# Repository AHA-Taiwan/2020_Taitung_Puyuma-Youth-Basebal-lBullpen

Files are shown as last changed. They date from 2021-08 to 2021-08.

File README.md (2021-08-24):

# 2020｜台東卑南｜少棒木構牛棚
## _Puyuma Youth Baseball Bullpen_, Taitung, Taiwan

>Humanitarian Architecture in Taitung<br/>
>
以台灣國產木材為主體構築材料之人道建築案例，主要材料來源自：行政院農業委員會林務局「台灣木材」標章、正昌製材有限公司「柳杉」及東皇昌五金工具有限公司。由與木製研設計，公東高工、大安高工與交通大學等學校單位合作進行實作，計畫透過國產材木構設計改善偏鄉少棒練習環境。<br/>

## 基地環境：<br/>
台灣東南地區，北回歸線以南，有焚風、颱風、東北季風，海風具高度鹽分，設計時需注意材料防潮防蝕保護。<br/>
* 基地環境氣象資料：https://www.cwb.gov.tw/V8/C/W/County/County.html?CID=10014 <br/>
* 氣象觀測歷史紀錄：<br/>
  https://e-service.cwb.gov.tw/HistoryDataQuery/DayDataController.do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 <br/>

* 台東縣氣候月平均氣溫、月平均降雨量、風速與相對濕度數據圖表<br/>
 （取自交通部中央氣象局，統計期間為 1991-2020 年）<br/>



* Google Map 位置：https://goo.gl/maps/4CSL8ehEizMw4Z4f6<br/>

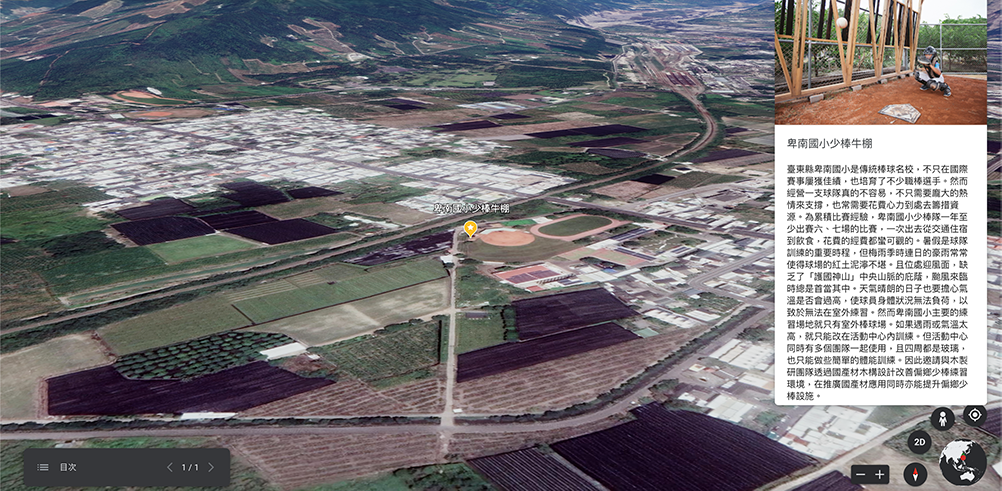
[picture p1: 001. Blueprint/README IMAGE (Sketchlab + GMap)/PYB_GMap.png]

***
## 專案介紹：<br/>
* 主要建材：台灣杉 [ 14.4 x 3 x 360 cm ]、[ 14.4 x 4.2 x 360 cm ] 和 [ 9.6 x 4.2 x 360 cm ] 尺寸。
* 數位模型［ 整體木構 3D ］：<br/>

捕手位置 Catcher's Position<br/>
Digital Model Link: https://skfb.ly/ooMID<br/> 
<br/>
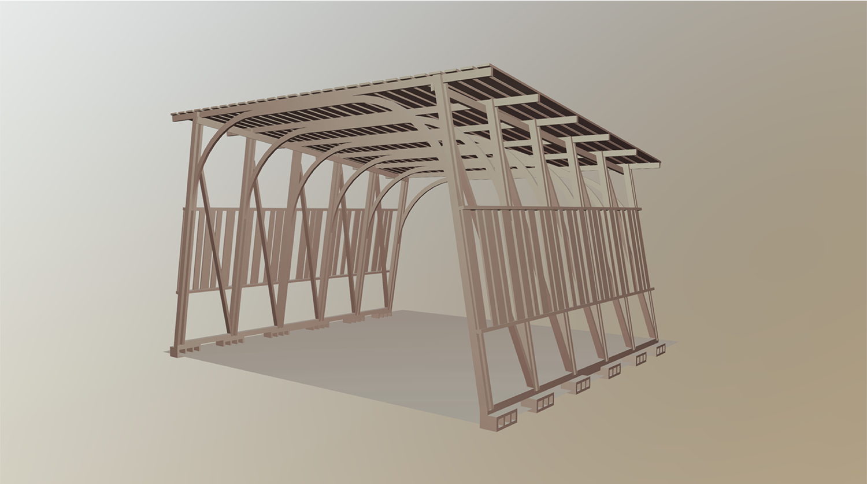
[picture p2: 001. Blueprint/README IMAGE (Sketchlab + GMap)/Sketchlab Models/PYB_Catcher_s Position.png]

<br/>
<br/>
投手位置 Pitcher's Position<br/>
Digital Model Link: https://skfb.ly/ooMI8<br/>
<br/>
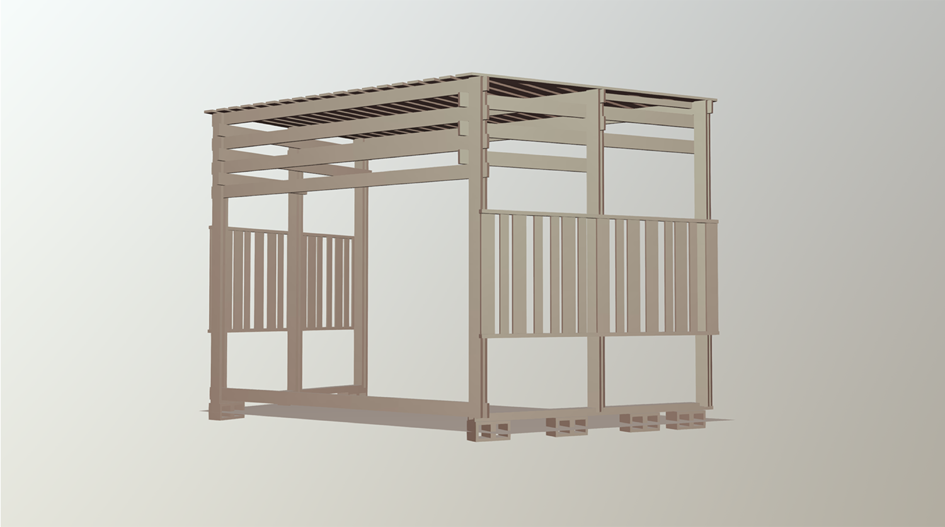
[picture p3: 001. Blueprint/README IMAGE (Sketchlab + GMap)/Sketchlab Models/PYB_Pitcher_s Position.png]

<br/>
<br/>
捕手區施工步驟（Construction Process of the Catcher's Position）<br/>
<br/>
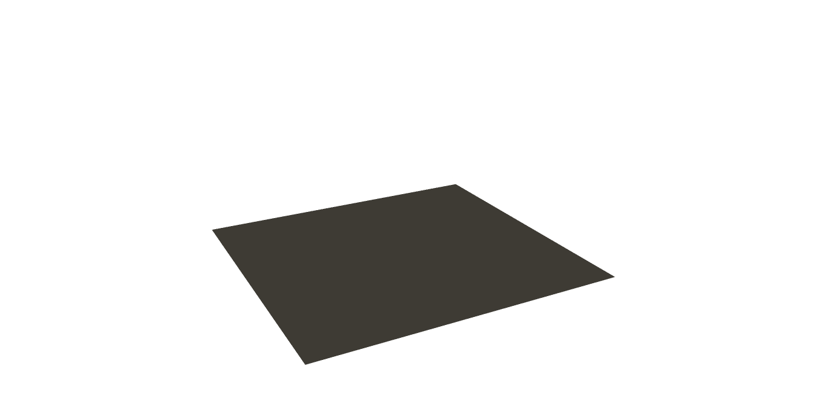
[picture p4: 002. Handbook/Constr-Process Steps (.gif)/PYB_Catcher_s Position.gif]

<br/>
<br/>
投手區施工步驟（Construction Process of the Pitcher's Position）<br/>
<br/>
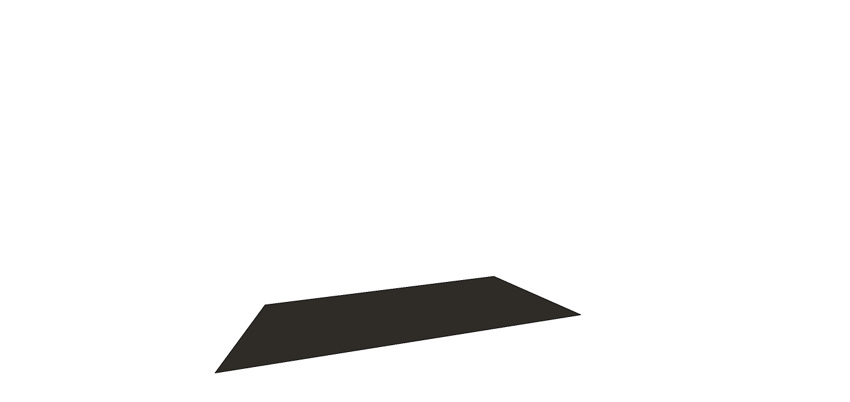
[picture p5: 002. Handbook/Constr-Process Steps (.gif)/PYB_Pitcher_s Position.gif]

<br/>
<br/>
***
## 如何達成合作建造：<br/>
* 請參閱［初次合作建造就上手 Collab-Const-Quick-Guide］：<br/>
https://github.com/AHA-Taiwan/Collab-Const-Quick-Guide/wiki <br/>
***
## 確保工作安全：<br/>
* 請參閱［合作建造-安全規範 Collab-Const-Safety］：<br/>
https://github.com/AHA-Taiwan/Collab-Const-Safety/wiki <br/>
***
## 探索合作資源：<br/>
* 請參閱［合作建造-資源探索 Collab-Const-Source］：<br/>
https://github.com/AHA-Taiwan/Collab-Const-Source/wiki <br/>
***
## 取得建造知識：<br/>
* 關於一般的常用構造技術（Techniques），請參閱［合作建造-學習知識 Collab-Const-Learning］：<br/>
https://github.com/AHA-Taiwan/Collab-Const-Learning/wiki <br/>
* 關於本案的特殊構築技術（Tectonic）， 請參閱［本案資料夾 002. Handbook］：<br/>
https://github.com/AHA-Taiwan/2020_Taitung_Puyuma-Youth-Baseball-Bullpen/tree/master/002.%20Handbook<br/>
***

> #### 歡迎參與專案開發，Branch合併可向專案管理者提出請求

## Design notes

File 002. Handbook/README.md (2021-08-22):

Assembly Drawing--組裝圖面<br/>
Assembly-Object Coding--物件組裝編碼<br/>
Constr-Process Handbook (pdf+ppt)--施工手冊與簡報<br/>
Constr-Process Sheet (.doc)--工項工序表<br/>
Constr-Processs Steps (.gif)--動態組裝圖<br/>
<br/>
Construction Method (photos)--施工工法<br/>
Link: https://drive.google.com/drive/folders/1FZwmxR8_8e2cyzcdbKTD-9hDnzFZ1XvT?usp=sharing<br/>

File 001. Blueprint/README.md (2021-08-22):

2D CAD (.dwg)<br/>
2D JPG<br/>
3D Models<br/>
3D Pictures<br/>
README IMAGE (Gmap & Sketchfab)<br/>

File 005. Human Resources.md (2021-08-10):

# 專業者佈局與人力成本紀錄 
主要紀錄整體施工過程中，專業者、準專業者、非專業者於不同工項所花費時數，從中可間接推估建造施工人力經費及時間成本。
專業者M、準專業者P、非專業者N，當地人加註C

## 一、基礎施工
|人力編碼|當地人|工作總時數(hrs)|請工|換工|志工|
|:-:|:-:|:-:|:-:|:-:|:-:|
|M01 | |12 | | |V |
|M02 | |12 | | |V |
|M03 | |12 | | |V |
|M04 | |12 | | |V |
|P01 | |12 | | |V |
|P02 | |12 | | |V |
|P04 | |12 | | |V |
|P05 | |12 | | |V |
|P06 | |12 | | |V |
|P07 | |12 | | |V |
|P08 | |12 | | |V |
|P09 | |12 | | |V |
|P010 | |12 | | |V |
***
## 二、捕手區結構
|人力編碼|當地人|工作總時數(hrs)|請工|換工|志工|
|:-:|:-:|:-:|:-:|:-:|:-:|
|M01 | |32 | | |V |
|M02 | |32 | | |V |
|M03 | |32 | | |V |
|M04 | |32 | | |V |
|P01 | |32 | | |V |
|P02 | |32 | | |V |
|P04 | |32 | | |V |
|P05 | |32 | | |V |
|P06 | |32 | | |V |
|P07 | |32 | | |V |
|P08 | |32 | | |V |
|P09 | |32 | | |V |
|P010 | |32 | | |V |
***
## 三、投手區結構
|人力編碼|當地人|工作總時數(hrs)|請工|換工|志工|
|:-:|:-:|:-:|:-:|:-:|:-:|
|M01 | |24 | | |V |
|M02 | |24 | | |V |
|M03 | |24 | | |V |
|M04 | |24 | | |V |
|P01 | |24 | | |V |
|P02 | |24 | | |V |
|P04 | |24 | | |V |
|P05 | |24 | | |V |
|P06 | |24 | | |V |
|P07 | |24 | | |V |
|P08 | |24 | | |V |
|P09 | |24 | | |V |
|P010 | |24 | | |V |
***

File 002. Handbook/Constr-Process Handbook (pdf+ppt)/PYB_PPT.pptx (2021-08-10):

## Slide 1

2020

卑南義築．工作手冊

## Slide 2

目錄

一．活動簡述．．．．．．．．．．．．１
二．自備物品與重要叮嚀．．．．．．．２
三．每日作息與行事曆．．．．．．．．４
四．交通與地圖．．．．．．．．．．．６
五．附件．．．．．．．．．．．．．．７
值日生班表
各組分工負責人
通訊錄
牛棚設計圖面
木材尺寸

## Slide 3

１

一．活動簡述

時間：2020年8月19日 —2020年8月28日
地點：台東縣卑南鄉卑南國小（台東縣台東市更生北路317號）
住宿：卑南國小主題教室

夏天是明亮的，太陽是辣的，
青春的心是熱血的。
離開了繁華，重返樸實；
捨棄了依賴，回歸自立。

參與團體

外界交流

大愛電視台
聯新文教基金會

台東縣政府文化處
公東高工
家具木工科／室內設計科／建築科
納樊斯木工作室
義築工具圖書館
老麥農場露營區
社團法人台東縣巴蘭文化發展協會
社團法人台灣義築協會

材料贊助

行政院農委會林務局
正昌製材（台灣杉）
誠豐木業（黃檜木）
東皇昌五金行

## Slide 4

２

二．自備物品與重要叮嚀

換洗衣物 | 輕便工作服／衣架／曬衣夾／塑膠袋／洗衣用具／肥皂
盥洗用品 | 潔牙用品／毛巾／沐浴用品／吹風機
個人衛生品 | 衛生紙／濕紙巾／生理用品
個人藥物 | 健保卡／防蚊液／防曬乳／藥膏／個人用藥
必備物品 | 手電筒／睡袋／麥克筆／抹布
餐具 | 環保餐具／水壺
其他 | 帽子／外套／雨具／筆記／糧食／相機／袖套 足夠的零用金＆快樂心

重要叮嚀

1. 校園蛇類出沒，夜間活動務必攜帶手電筒，並尊重當地生態環境 。
2. 為避免影響施工進度，請按作息表活動，請勿飲酒 。
3. 避免使用香味濃郁的盥洗用品，易引來蚊蟲 。
4. 請留意貴重物品 。
5. 請注意當地禁忌，活動請結伴同行 。
6. 當地提款與融資服務不便，請攜帶足夠的現金 。
7. 施工區域內請著長褲及全包覆鞋，勿穿拖鞋或涼鞋，並時時補充水分。
8. 由於浴室數量有限，洗澡時間限制十分鐘。

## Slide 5

３

最重要的三件事！！
1. 晚間收工前30分鐘，清點材料、工具
2. 收工前15分鐘，整理工作環境
3. 工地危險，務必攜帶安全帽著長褲及全包覆鞋，勿著涼拖鞋
-工具配件務必妥善放回它的位置，切勿亂放
-建材勿隨意放置，會影響材料品質與建築壽命
-廢料勿扔棄，做好資源管理，這是對建築過程的尊重
-離隊務必告知組員、組長，個人行為將影響全體
-注意言行、態度，對自己負責，也尊重合作夥伴
-我們是一個大團體，務必保持與其他單位的良好互動
-我們是一個共同體，請關心身邊的伙伴，發揮自己的價值

施工注意事項

做一個謙卑的實踐者，感恩這份學習的機會

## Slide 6

４

三．每日作息與行事曆

（時間可能依每日天候狀況有所調整）

時間 | 活動 | 備註
0600 | Good Morning | 宿舍長叫醒大家
0600–0630 | 盥洗準備
0630–0700 | 活力早餐 | 生活組提前準備
0700–1130 | 牛棚建起來 | 施工組開工
1130–1300 | 午餐輕巧吃 | 生活組準備
1300–1700 | 牛棚繼續建起來 | 施工組開工
1700–1800 | 洗澎澎 | 超時斷水電！
1800–1930 | 晚餐時光 | 生活組準備
1930–2100 | 工作會議 | 進度／工地狀況檢討
2100–2200 | 小組／個人時間 | 工作日誌／影音整理
2200 | 睡飽睡好

生活值日生工作
1. 工作環境整理
2. 餐後、廚餘整理
3. 清洗、收拾餐具
4. 搬運、發放食物

住宿值日生工作
1. 寢室環境清潔
2. 廁所清潔及垃圾清理
3. 浴廁清潔

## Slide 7

５

行事曆

08/19 （三）

認識大家／基礎前置加工

08/21 （五）

08/20 （四）

08/23 （日）

08/22 （六）

08/24 （一）

08/25 （二）

08/26 （三）

08/27 （四）

08/28 （五）

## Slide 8

６

四．交通與地圖

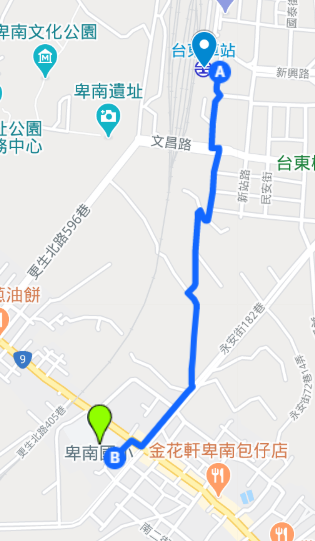
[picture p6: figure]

集合

加工、施工

住宿

※ 抵達臺東車站後，基本上都是縣府派車支援！

由　臺東車站　前往　初鹿國中

步行（15分鐘）至南王站牌
搭乘8171號公車（45分鐘）至初鹿國中

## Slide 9

７

五．附件

各組分工負責人

生活
交通／宿舍長
工程
工具
材料
攝影
護理

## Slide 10

10

牛棚設計圖面

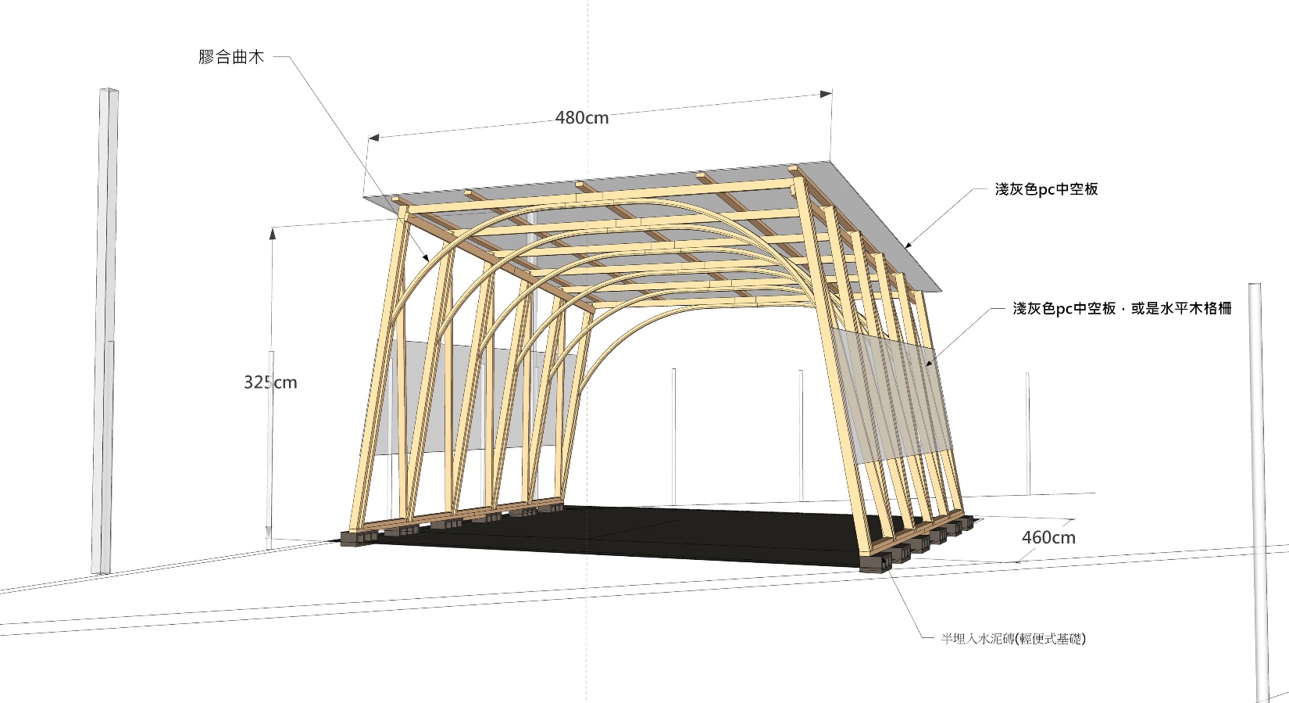
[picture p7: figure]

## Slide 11

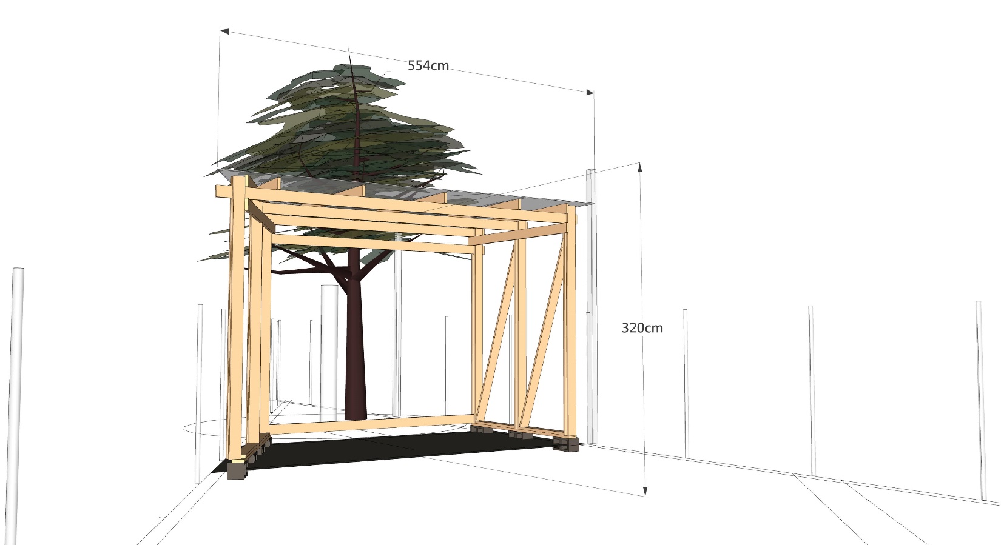
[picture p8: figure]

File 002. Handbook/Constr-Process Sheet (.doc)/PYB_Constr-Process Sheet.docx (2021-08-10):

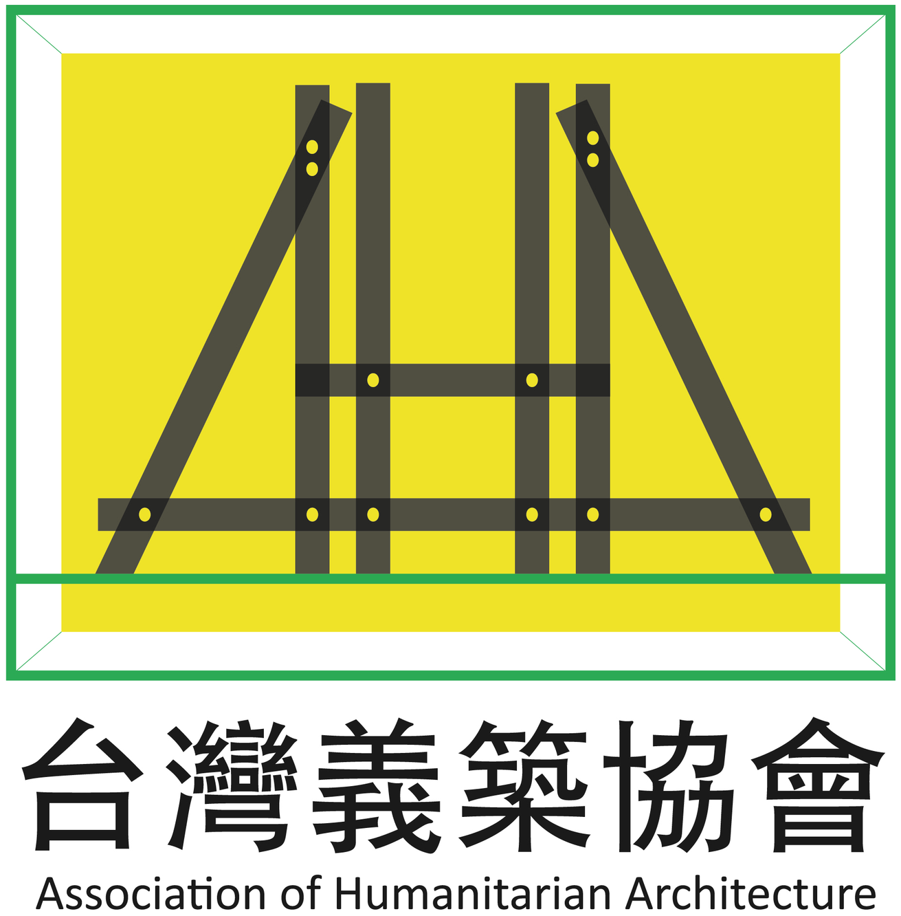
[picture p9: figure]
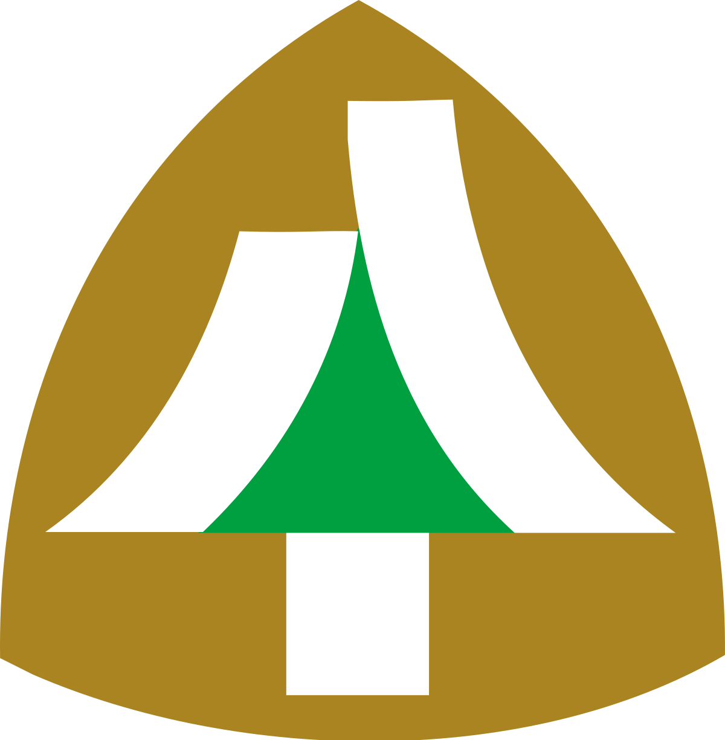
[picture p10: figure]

2020年 台東卑南少棒牛棚 義築作品

生產製程文件

作業名稱 | 一、構件預製 | 項次 | 作業順序 | | 備註

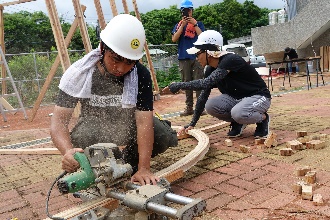
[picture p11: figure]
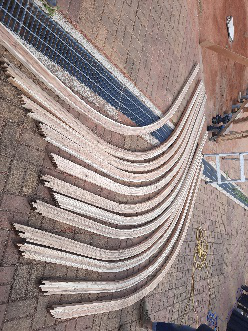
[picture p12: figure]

項次1-2 項次1 項次2 | | 1 | 預製曲樑 | | 與木製研工廠預製
| | 2 | 將木材切割至構件尺寸
| | 項次 | 原料 | 設備 | 站別
| | a | 斷面14.4*4.2cm木料 斷面14.4*3cm木料 斷面9.6*4.2cm木料 | 工作臺 | 加工區
| | b | 斷面14.4*4.2cm木料 斷面14.4*3cm木料 斷面9.6*4.2cm木料 | 角切機 | 切割區

作業名稱 | 二、燒杉 | 項次 | 作業順序 | | 備註

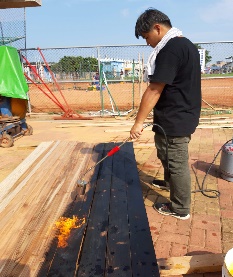
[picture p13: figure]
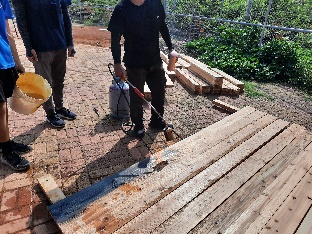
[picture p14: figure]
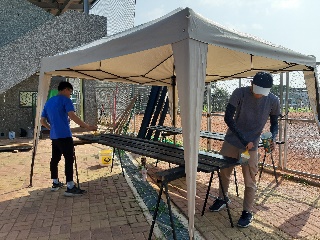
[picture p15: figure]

項次1-2 項次1 項次2 | | 1 | 燒杉
| | 2 | 冷卻
| | 3 | 確認燃燒程度
| | 4 | 上保護漆
| | 項次 | 原料 | 設備 | 站別
| | a | 斷面14.4*4.2cm木料 斷面14.4*3cm木料 斷面9.6*4.2cm木料 | 火槍 瓦斯 | 燒杉區
| | b | 斷面14.4*4.2cm木料 斷面14.4*3cm木料 斷面9.6*4.2cm木料 | 灑水 | 燒杉區
項次3 項次4 | | c | 斷面14.4*4.2cm木料 斷面14.4*3cm木料 斷面9.6*4.2cm木料 | 目視 | 燒杉區
| | d | 斷面14.4*4.2cm木料 斷面14.4*3cm木料 斷面9.6*4.2cm木料 | 油漆刷 護木漆 | 油漆區

作業名稱 | 三、捕手區結構施工 | 項次 | 作業順序 | | 備註

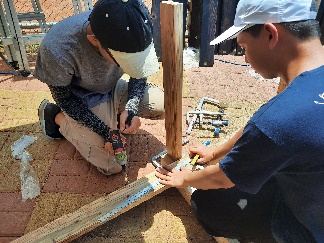
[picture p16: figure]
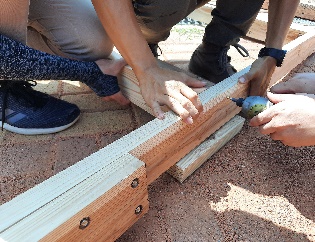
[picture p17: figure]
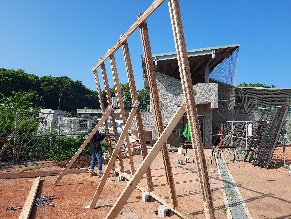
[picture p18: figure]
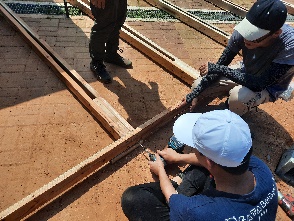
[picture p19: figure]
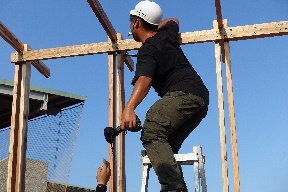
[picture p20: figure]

項次1 項次2 項次3 項次4 項次5 項次6 | | 1 | 接合延長木頭
| | 2 | 放樣立柱位置
| | 3 | 立柱於基座上
| | 4 | 斜撐假固定
| | 5 | 上大樑
| | 6 | 上曲樑
| | 項次 | 原料 | 設備 | 站別
| | a | 已加工木料、螺桿 | 起子機、電鑽 | 組裝區
| | b | 已加工木料 | 尺、筆 | 組裝區
| | c | 已加工木料、螺桿 | 電鑽、起子機 | 組裝區
| | d | 木料 | 夾具 | 切割區
| | e | 已裁切木料、螺桿 | 起子機、電鑽 | 組裝區
| | f | 已裁切木料、螺桿 | 起子機、電鑽 | 組裝區

作業名稱 | 四、投手區結構施工 | 項次 | 作業順序 | | 備註

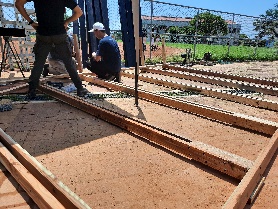
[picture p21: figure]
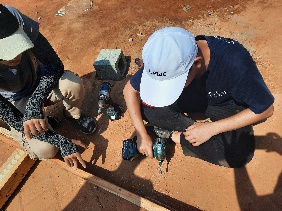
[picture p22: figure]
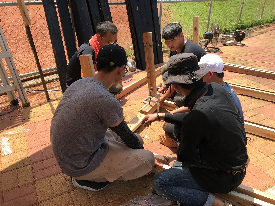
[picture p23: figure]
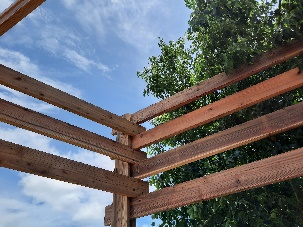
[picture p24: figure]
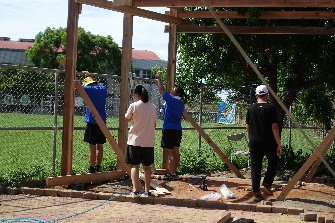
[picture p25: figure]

項次1 項次2 項次3 項次4 項次5 項次6 | | 1 | 接合延長木頭
| | 2 | 放樣立柱位置
| | 3 | 立柱於基座上
| | 4 | 後方橫樑施作
| | 5 | 側邊橫樑施作
| | 6 | 上大樑
| | 項次 | 原料 | 設備 | 站別
| | a | 已加工木料、螺桿 | 起子機、電鑽 | 組裝區
| | b | 已加工木料 | 尺、筆 | 組裝區
| | c | 已加工木料、螺桿 | 電鑽、起子機 | 裁切區
| | d | 已裁切木料、螺桿 | 電鑽、起子機 | 組裝區
| | e | 已裁切木料、螺桿 | 起子機、電鑽 | 組裝區
| | f | 已裁切木料、螺桿 | 起子機、電鑽 | 組裝區

作業名稱 | 五、上屋頂板 | 項次 | 作業順序 | | 備註

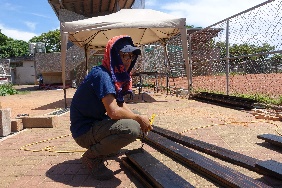
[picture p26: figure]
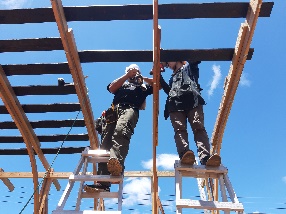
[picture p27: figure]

項次1 項次2 項次3 項次4 | | 1 | 確認組裝部件
| | 2 | 預排屋頂版位置
| | 3 | 釘槍固定接合處
| | 4 | 螺絲鎖上屋頂板
| | 項次 | 原料 | 設備 | 站別
| | a | 已燒杉木料 | 目視 | 組裝區
| | b | 已燒杉木料 | 人力 | 組裝區
| | c | 已燒杉木料 | 釘槍 | 組裝區
| | d | 已燒杉木料、螺絲 | 起子機 | 組裝區

作業名稱 | 六、窗框、窗板 | 項次 | 作業順序 | | 備註

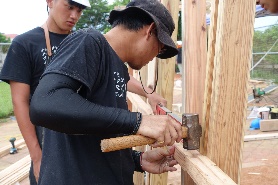
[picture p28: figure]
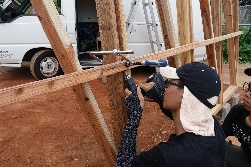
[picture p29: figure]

項次1 項次2 項次3 項次4 項次5 項次6 | | 1 | 下窗框引排水孔
| | 2 | 下窗框放樣、定水平
| | 3 | 上窗框定高度、水平
| | 4 | 假固定
| | 5 | 將窗框鎖於柱上
| | 6 | 放入窗板
| | 項次 | 原料 | 設備 | 站別
| | a | 已裁切木料 | 電鑽 | 組裝區
| | b | 已裁切木料 | 人力、水平尺、筆 | 組裝區
| | c | 已裁切木料 | 人力、水平尺、筆 | 組裝區
| | d | ----- | 夾具、釘槍 | 組裝區
| | e | 已裁切木料 | 電鑽、起子機 | 組裝區
| | f | 已燒杉木料 | 人力 | 組裝區

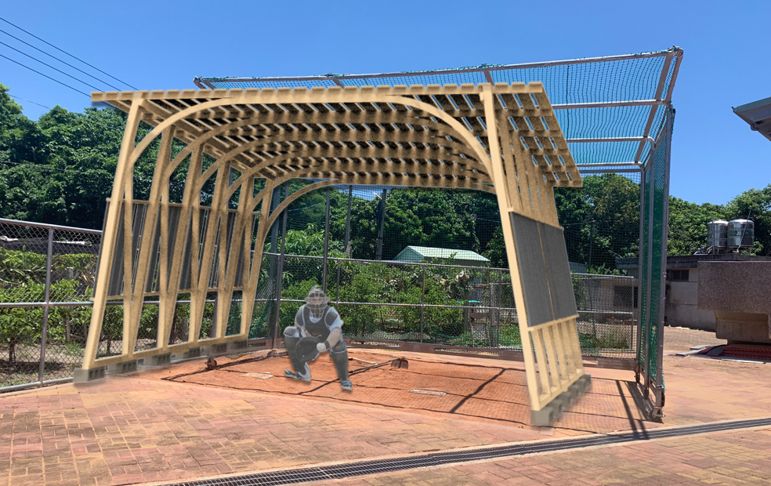
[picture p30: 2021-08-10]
001. Blueprint/3D Pictures/PYB_Catcher Side_Rendered.jpg

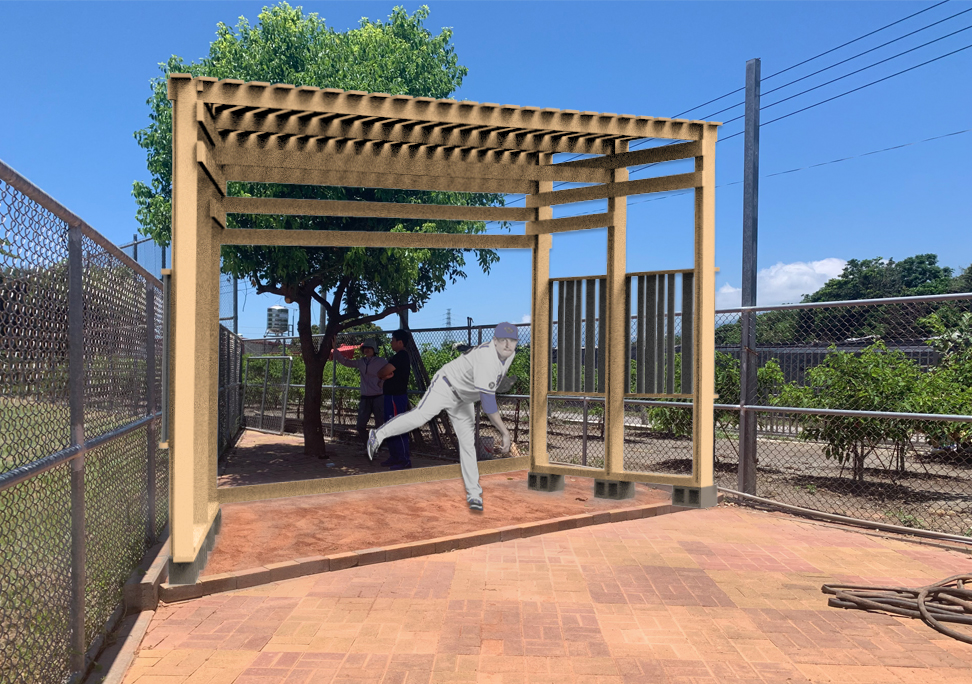
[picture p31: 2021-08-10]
001. Blueprint/3D Pictures/PYB_Pitcher Side_Rendered.jpg

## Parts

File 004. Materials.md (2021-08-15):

# 材料清單與部件編碼紀錄 
主要紀錄整體施工過程中，各部位構件之材料名稱、規格、數量、單價、材料來源、廠商資訊等，從中可推估材料經費及運輸成本。

## 主要建材
|編碼|材料名稱|部件位置|規格|需要數量|實購數量|材料來源|
|:-:|:-:|:-:|:-:|:-:|:-:|:-:|
|S001|柳杉|捕手區主體結構|9.6 x 4.2 x 360 cm|40|40|[正昌製材](http://www.wood.jen.com.tw/fengxi/front/bin/home.phtml)|
|S002|柳杉|投手區主體結構|14.4 x 4.2 x 360 cm|100|100|[正昌製材](http://www.wood.jen.com.tw/fengxi/front/bin/home.phtml)|
|S003|柳杉|屋頂平板|14.4 x 3 x 360 cm|100|100|[正昌製材](http://www.wood.jen.com.tw/fengxi/front/bin/home.phtml)|
***
## 五金材料
|編碼|材料名稱|部件位置|規格|數量|
|:-:|:-:|:-:|:-:|:-:|
|B001|護木漆||||
***

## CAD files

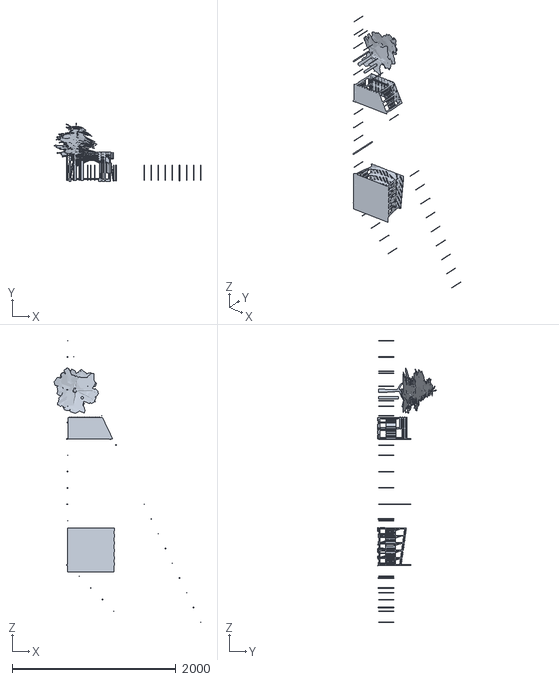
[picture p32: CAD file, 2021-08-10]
001. Blueprint/3D Models/PYB_Model.obj
1793.9 x 718.2 x 3447.3

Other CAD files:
001. Blueprint/2D CAD (.dwg)/PYB_Pitcher and Catcher_Model.dwg
001. Blueprint/2D CAD (.dwg)/PYB_Pitcher and Catcher_Plan.dwg
001. Blueprint/3D Models/PYB_Model(1).skp
001. Blueprint/3D Models/PYB_Model.3dm
001. Blueprint/3D Models/PYB_Model.skp

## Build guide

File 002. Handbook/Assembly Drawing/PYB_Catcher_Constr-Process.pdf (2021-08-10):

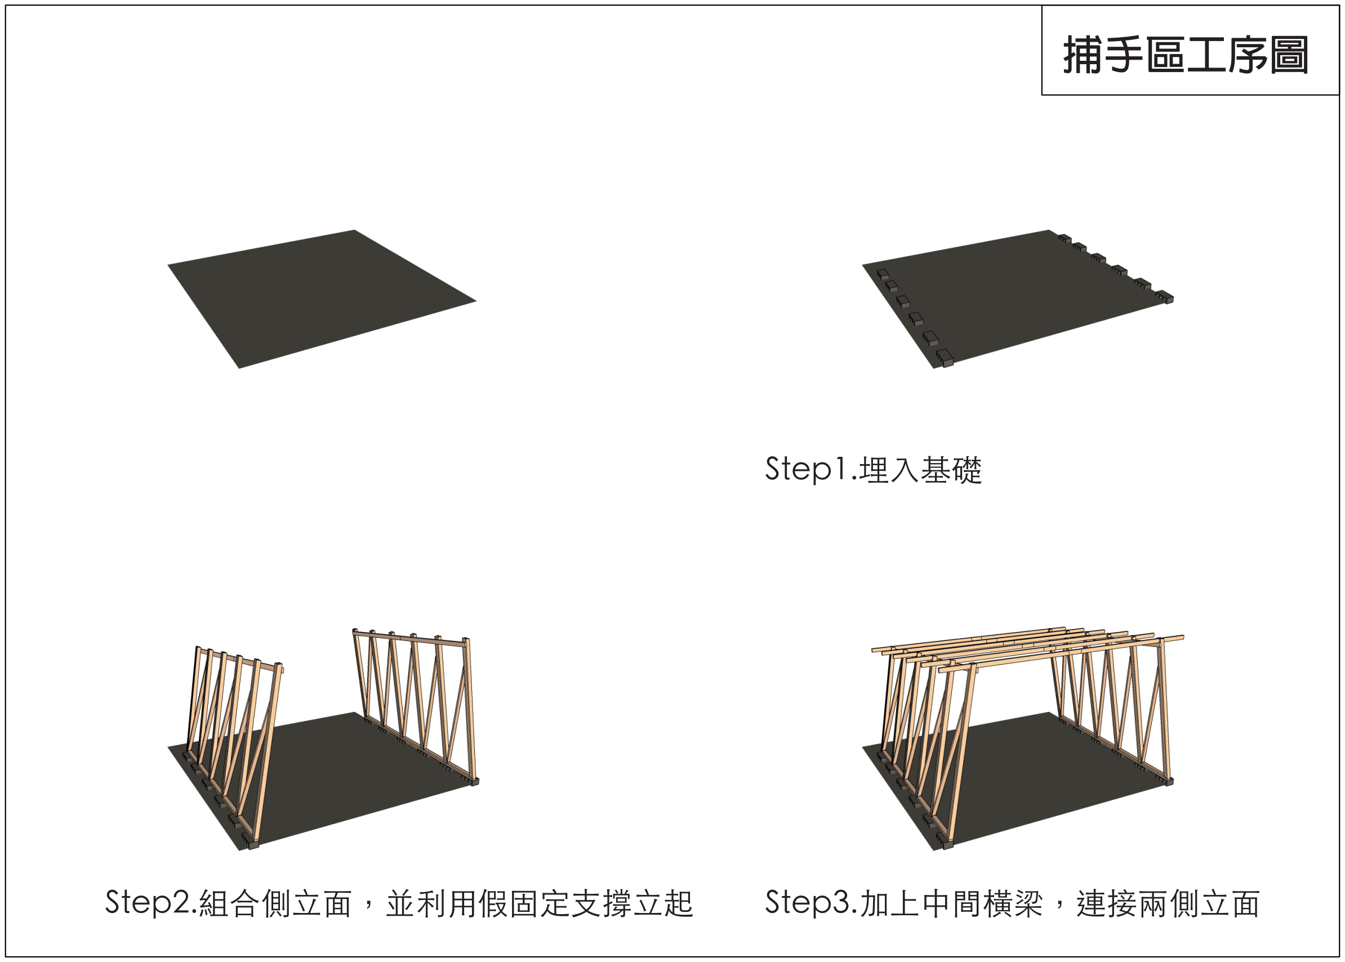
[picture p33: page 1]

Step2.組合側立面，並利用假固定支撐立起

Step1.埋入基礎

Step3.加上中間橫梁，連接兩側立面

捕手區工序圖

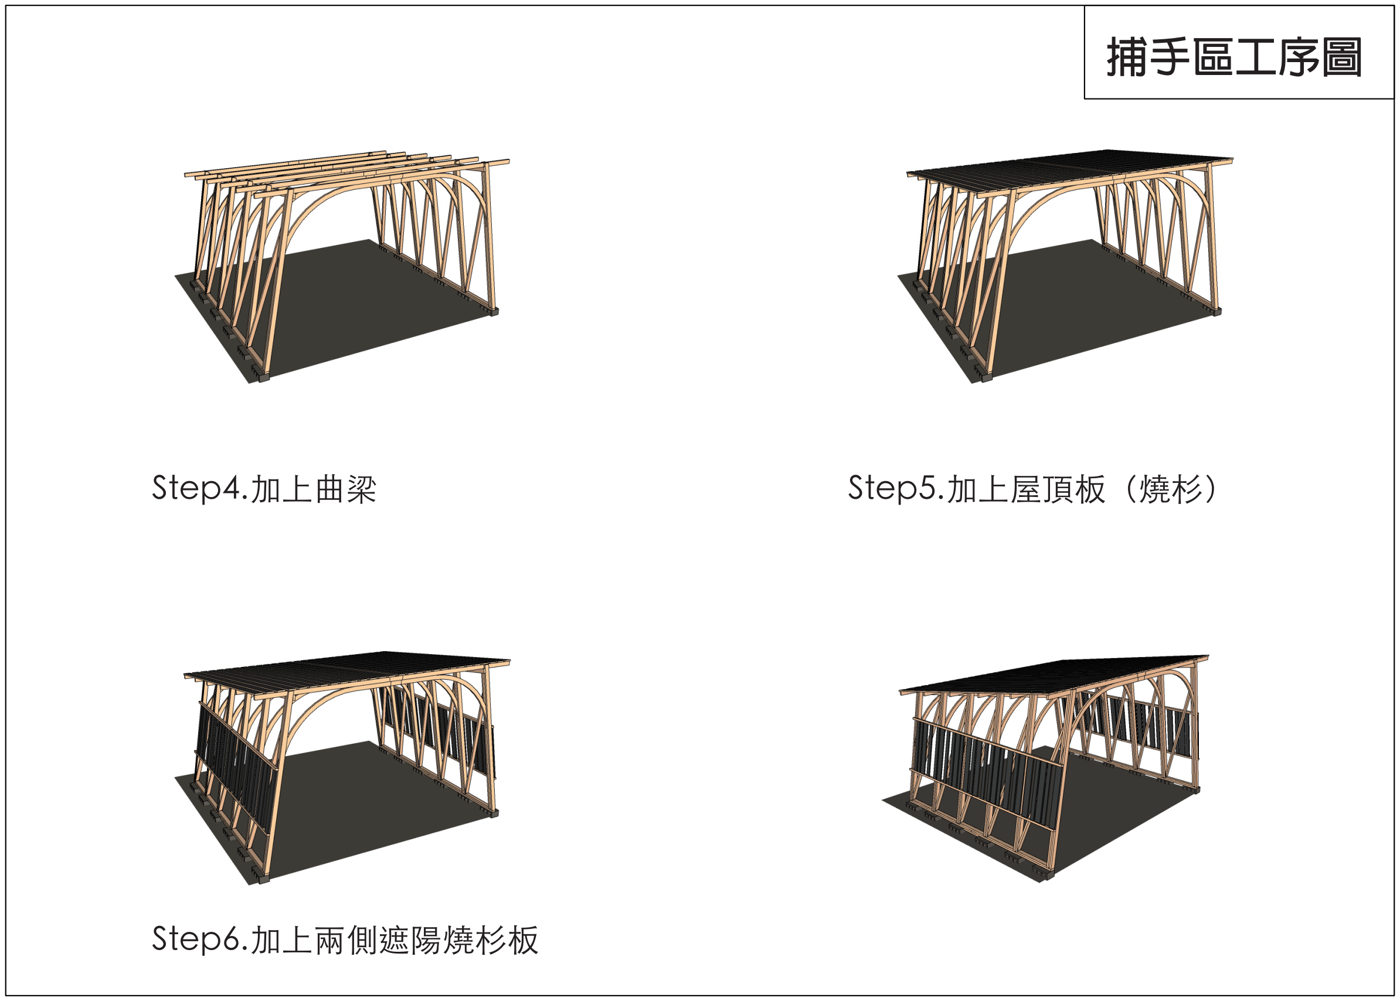
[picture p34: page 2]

Step4.加上曲梁 | Step5.加上屋頂板（燒杉）

Step6.加上兩側遮陽燒杉板

捕手區工序圖

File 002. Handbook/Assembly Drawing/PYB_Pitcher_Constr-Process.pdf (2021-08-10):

Step1.埋入基礎 | Step2.組合側立面，並利用假固定 支撐立起

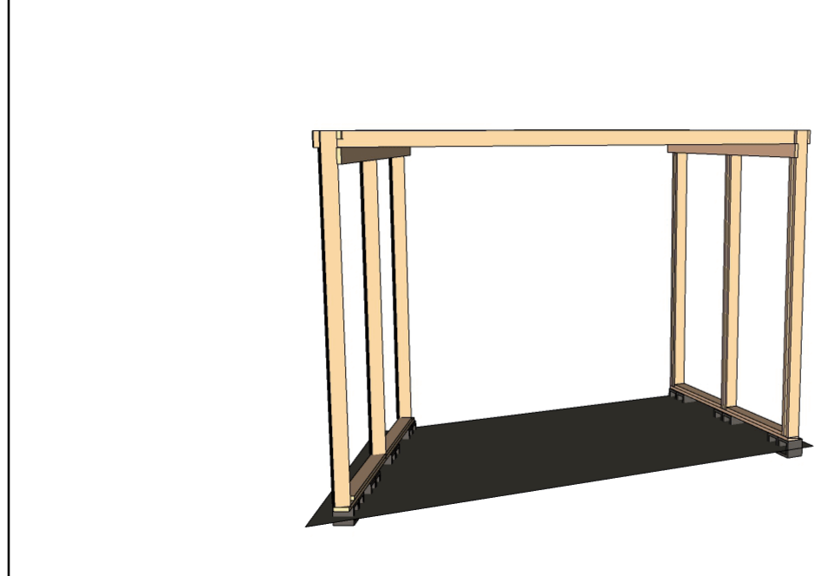
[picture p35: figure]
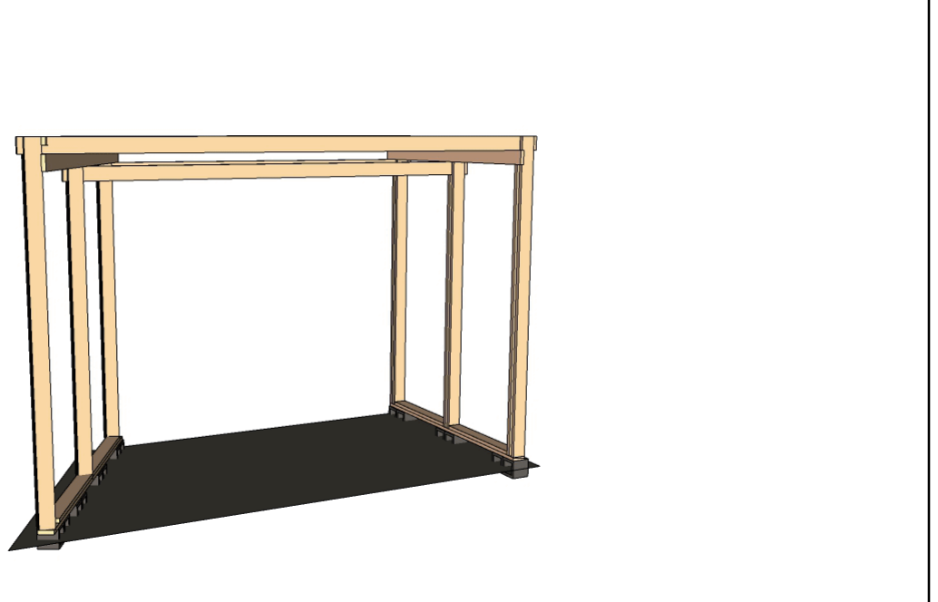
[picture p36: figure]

Step3.加上頂部大梁連接立面 | Step4.由上而下依序加上側邊橫梁

投手區工序圖

投手區工序圖

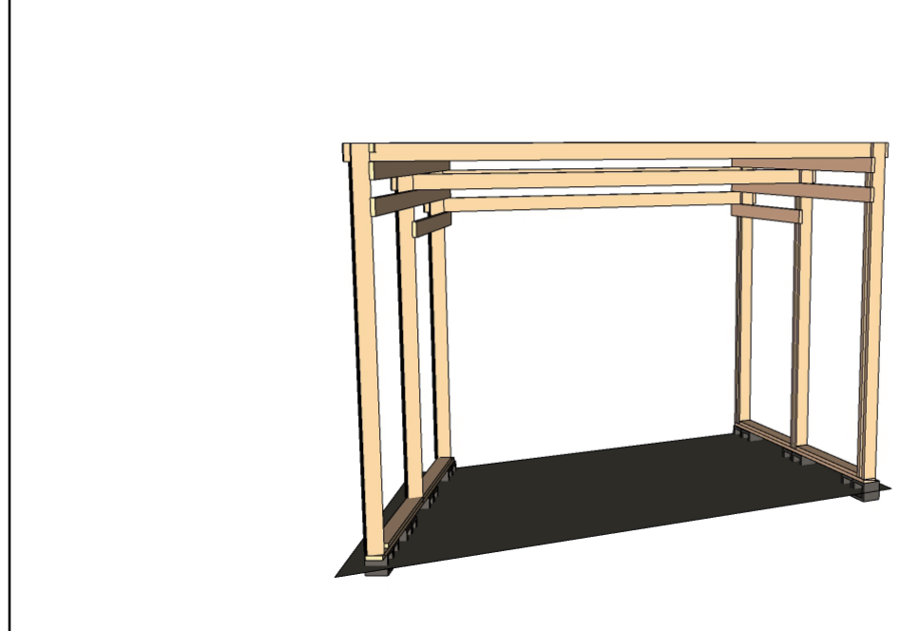
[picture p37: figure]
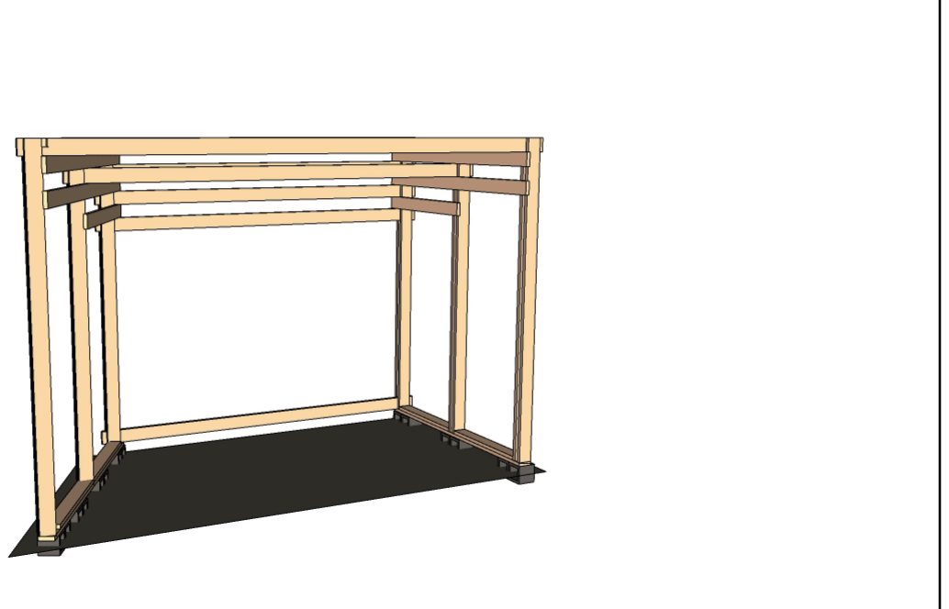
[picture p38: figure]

Step4.由上而下依序加上側邊橫梁 | Step4.由上而下依序加上側邊橫梁
Step4.由上而下依序加上側邊橫梁 | Step4.由上而下依序加上側邊橫梁

Step6.加上兩側遮陽燒杉板

投手區工序圖

Step5.加上屋頂板（燒杉）

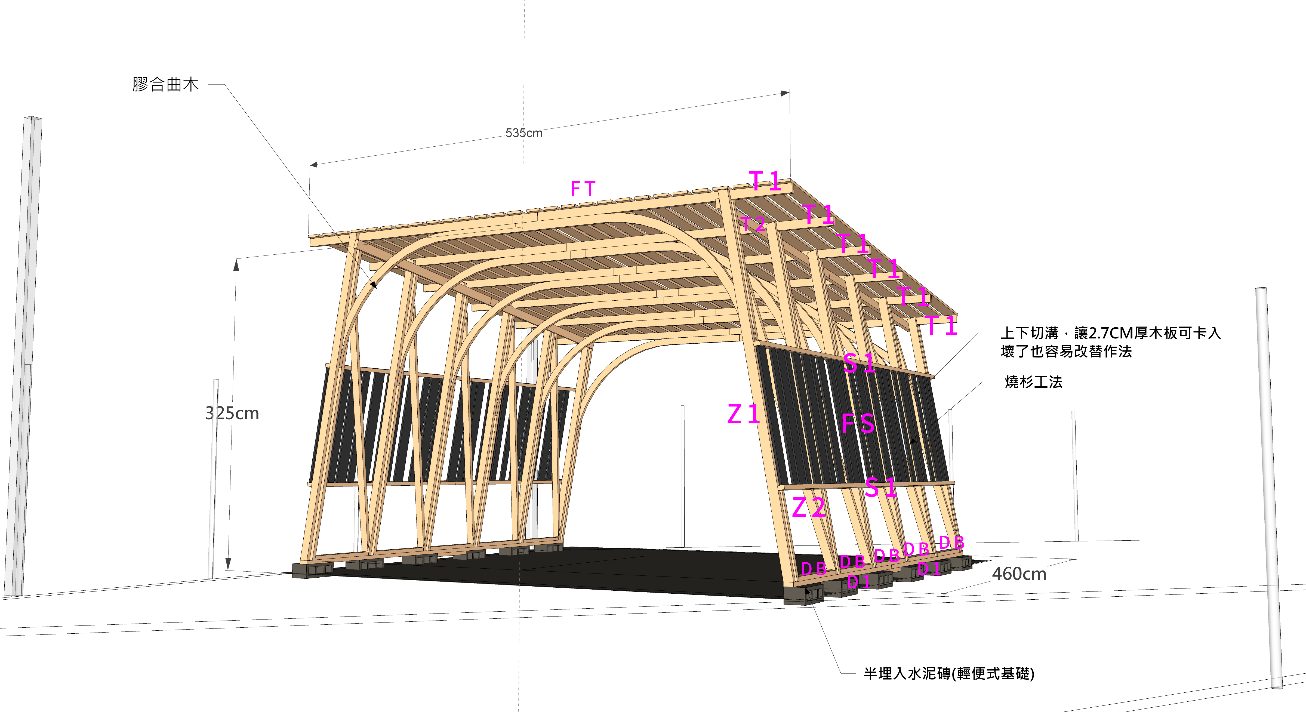
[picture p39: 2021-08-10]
002. Handbook/Assembly-Object Coding/PYM_Catcher_s Positionn_Coding.jpeg

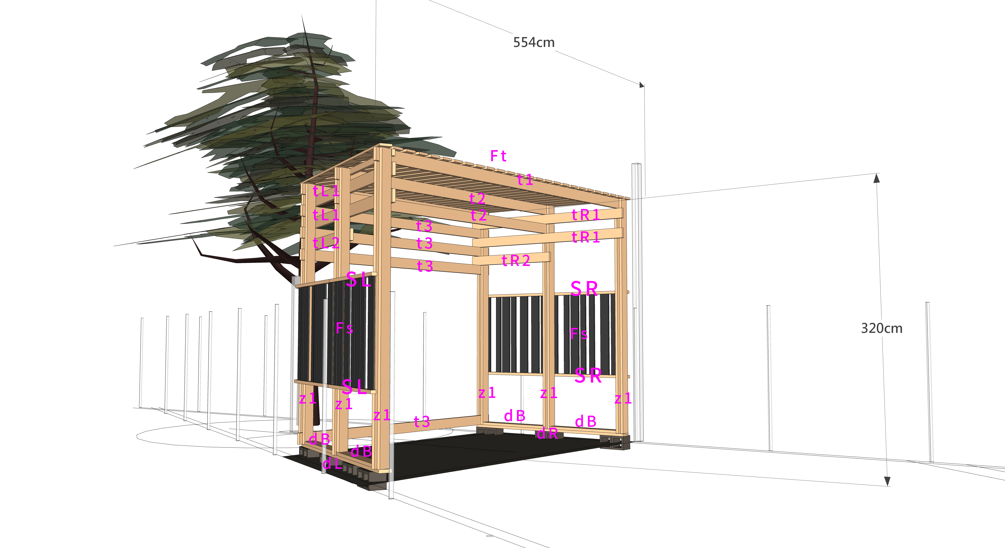
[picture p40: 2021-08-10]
002. Handbook/Assembly-Object Coding/PYM_Pitcher_s Position_Coding.jpeg

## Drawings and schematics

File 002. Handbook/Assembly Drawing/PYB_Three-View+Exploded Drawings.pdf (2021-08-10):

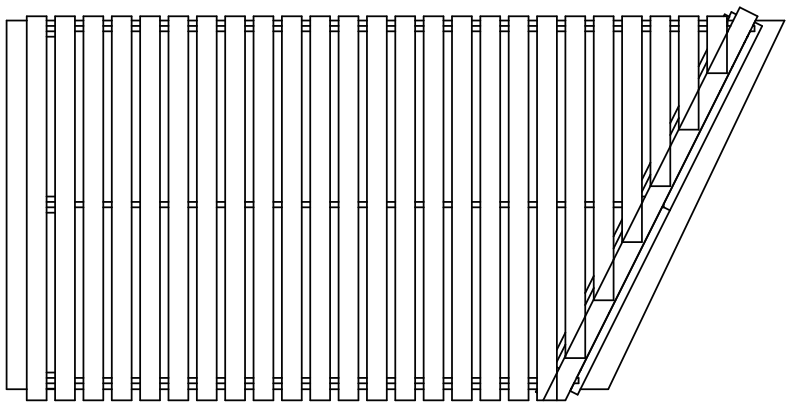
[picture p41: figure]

554cm

投手區三視圖

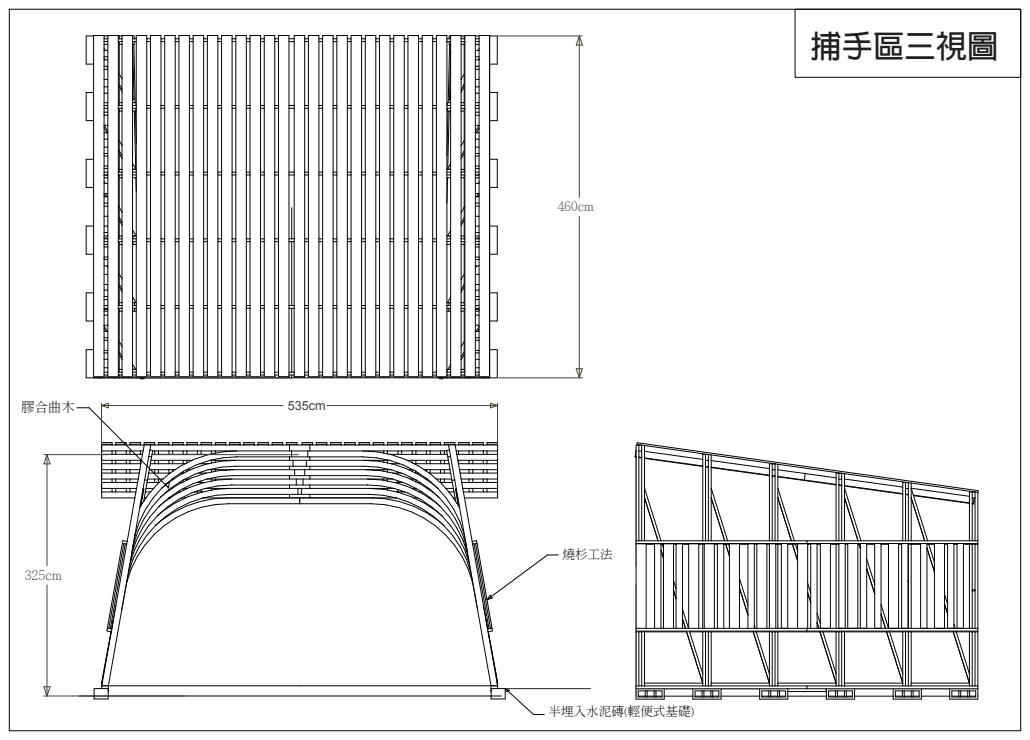
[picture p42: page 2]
膠合曲木; 半埋入水泥磚(輕便式基礎); 燒杉工法; 捕手區三視圖

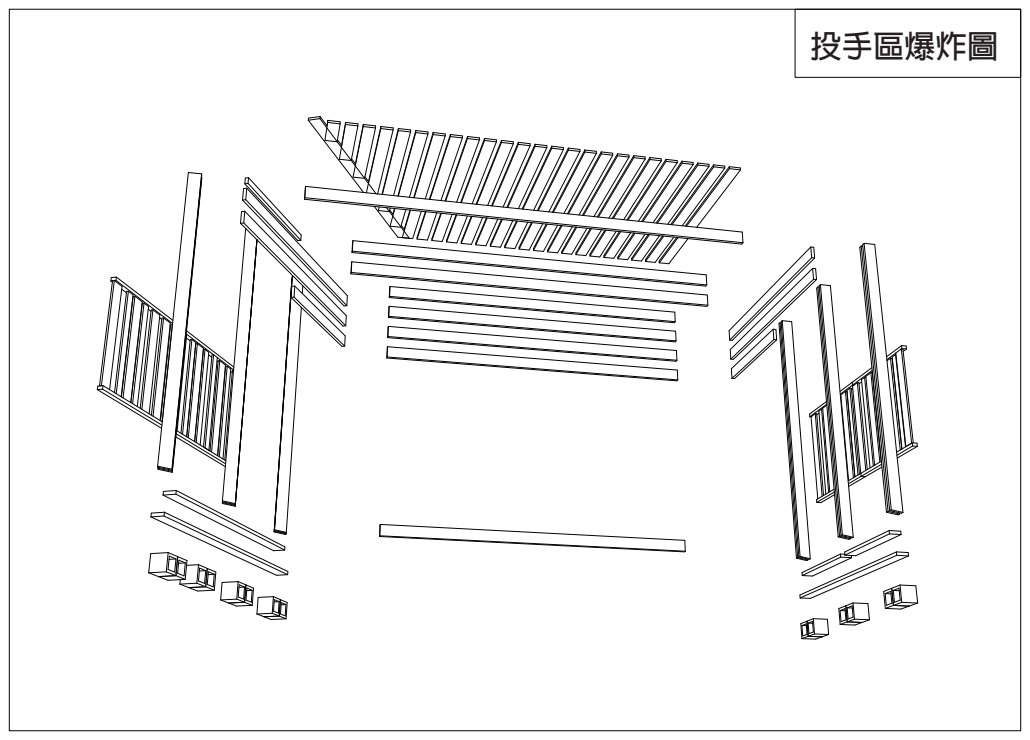
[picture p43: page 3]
投手區爆炸圖

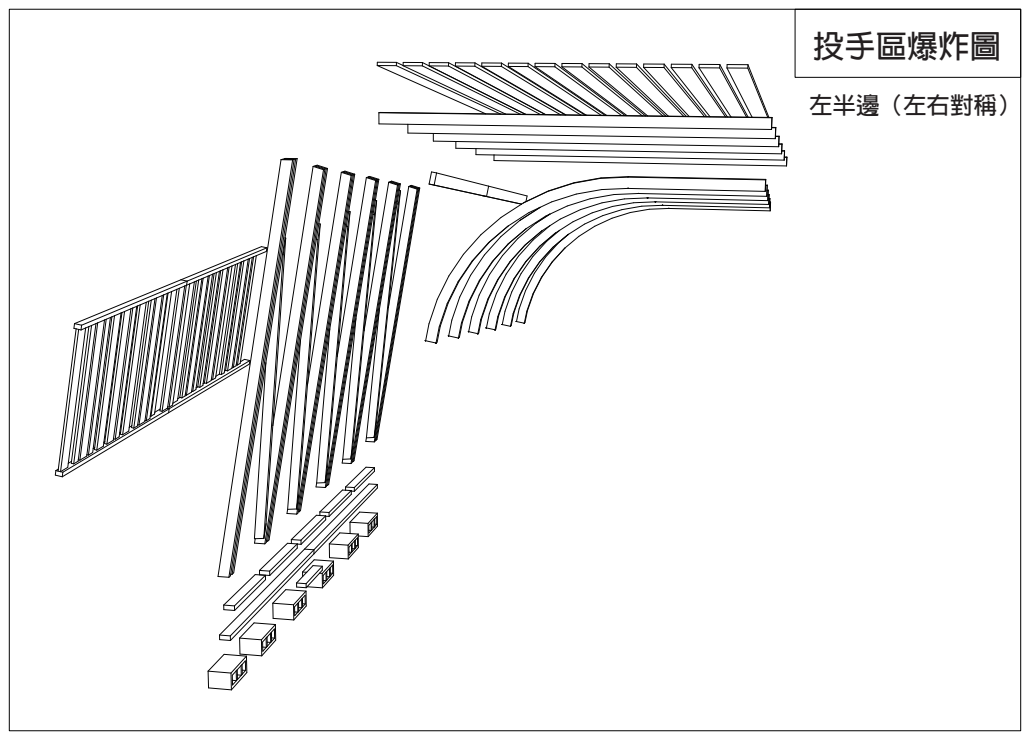
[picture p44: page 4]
投手區爆炸圖; 左半邊（左右對稱）

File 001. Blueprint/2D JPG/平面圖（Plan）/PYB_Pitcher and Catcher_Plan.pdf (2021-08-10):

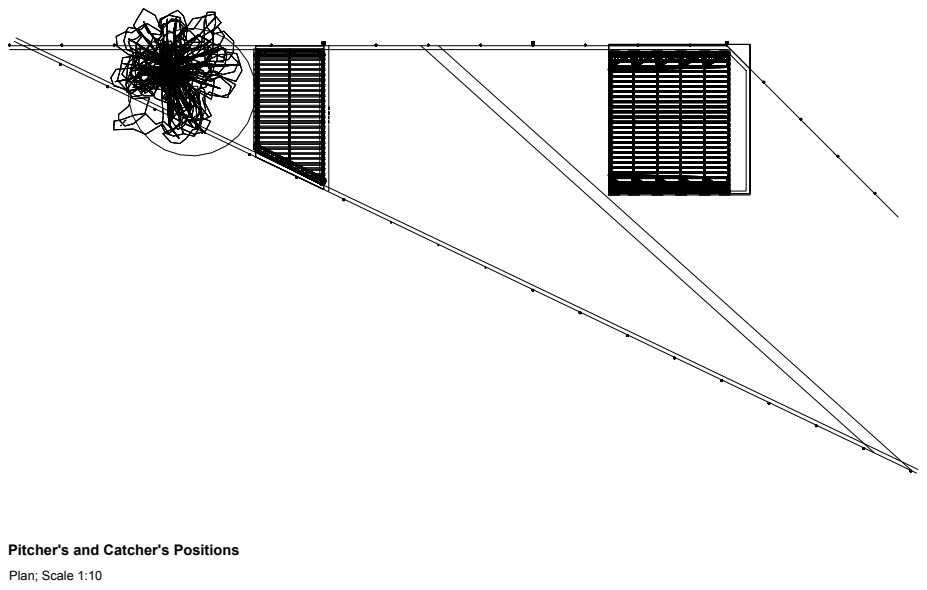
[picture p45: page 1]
Plan; Scale 1:10

Pitcher's and Catcher's Positions

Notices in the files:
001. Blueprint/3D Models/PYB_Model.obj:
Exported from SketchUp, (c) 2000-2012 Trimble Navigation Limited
